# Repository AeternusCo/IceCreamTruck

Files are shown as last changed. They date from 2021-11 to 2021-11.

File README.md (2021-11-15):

# Ice Cream Truck

A drop-in replacement PCB for Minivan cases with choc v1 switches.

**N.B.** At the date of publication, some keys don't exist so they'll either need to use smaller key sizes or 3d printed keys.

PCB has been tested, but order at your own risk.

## Features

- STM32F072 (or F042) MCU
- Drop-in compatibility with existing minivan cases
- Choc v1 switch footprints

## Firmware

ICT runs QMK. Firmware has not been merged into upstream, but should be available in the AeternusCo fork [here](https://github.com/AeternusCo/qmk_firmware).

## Ordering

Generate gerbers, upload to fab house of your choice, pay.

## Images

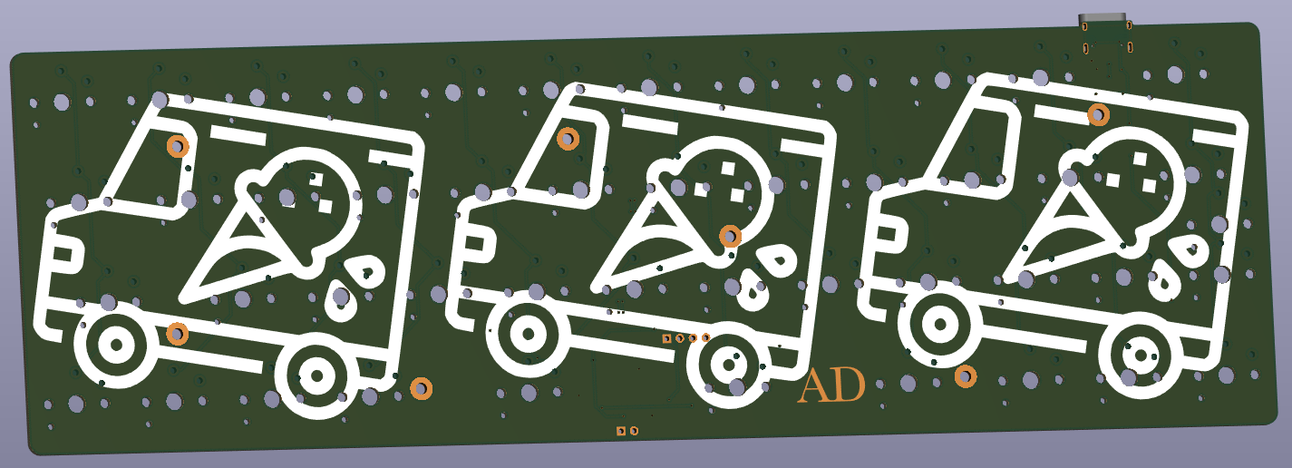
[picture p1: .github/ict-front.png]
PCB Front


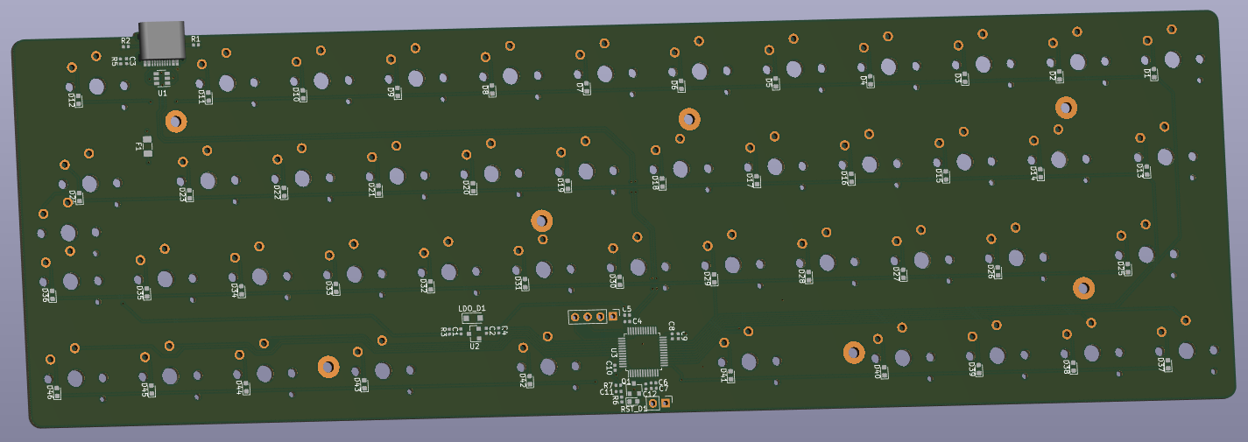
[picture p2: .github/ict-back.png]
PCB Back


## License

All files are licensed under CERN-OHL-P v2.

See [LICENSE](/LICENSE) file for more details.

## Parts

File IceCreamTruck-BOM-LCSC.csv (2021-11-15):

Id | Comment | Designator | Footprint | Quantity | LCSC Part Number
5 | 1N4148W | D38,D39,D37,D45,D46,D44,D16,D15,D13,D14,D8,D6,D7,D3,D4,D5,D2,D17,D18,D19,D20,D25,D26,D27,D28,D29,D30,D31,D32,RST_D1,D10,D12,D11,D9,D1,D22,D21,D23,D24,D33,D34,D35,D36,D40,D41,D43,D42 | 0603 | 47 | C109002
8 | STM32F072CBTx | U3 | LQFP-48_7.0x7.0x0.5P | 1 | C88447
9 | SRV05-4 | U1 | SOT-23-6 | 1 | C85364
10 | MCP1700T-3302E_SOT23 | U2 | SOT-23-3 | 1 | C39051
11 | 10u | C7,C11 | 0402 | 2 | C15525
12 | 1u | C1,C2,C6 | 0402 | 3 | C52923
13 | 4.7n | C3 | 0402 | 1 | C1538
14 | 100nF | C8,C4,C9,C12 | 0402 | 4 | C1525
15 | 4.7u | C5,C10 | 0402 | 2 | C23733
16 | 5k1 | R2,R1 | 0402 | 2 | C25905
17 | DTC123JKAT146 | Q1 | SOT-23-3 | 1 | C111724
22 | 100k | R3,R4 | 0402 | 2 | C25741
23 | 330k | R6 | 0402 | 1 | C25779
24 | 1M | R5,R7 | 0402 | 2 | C26083

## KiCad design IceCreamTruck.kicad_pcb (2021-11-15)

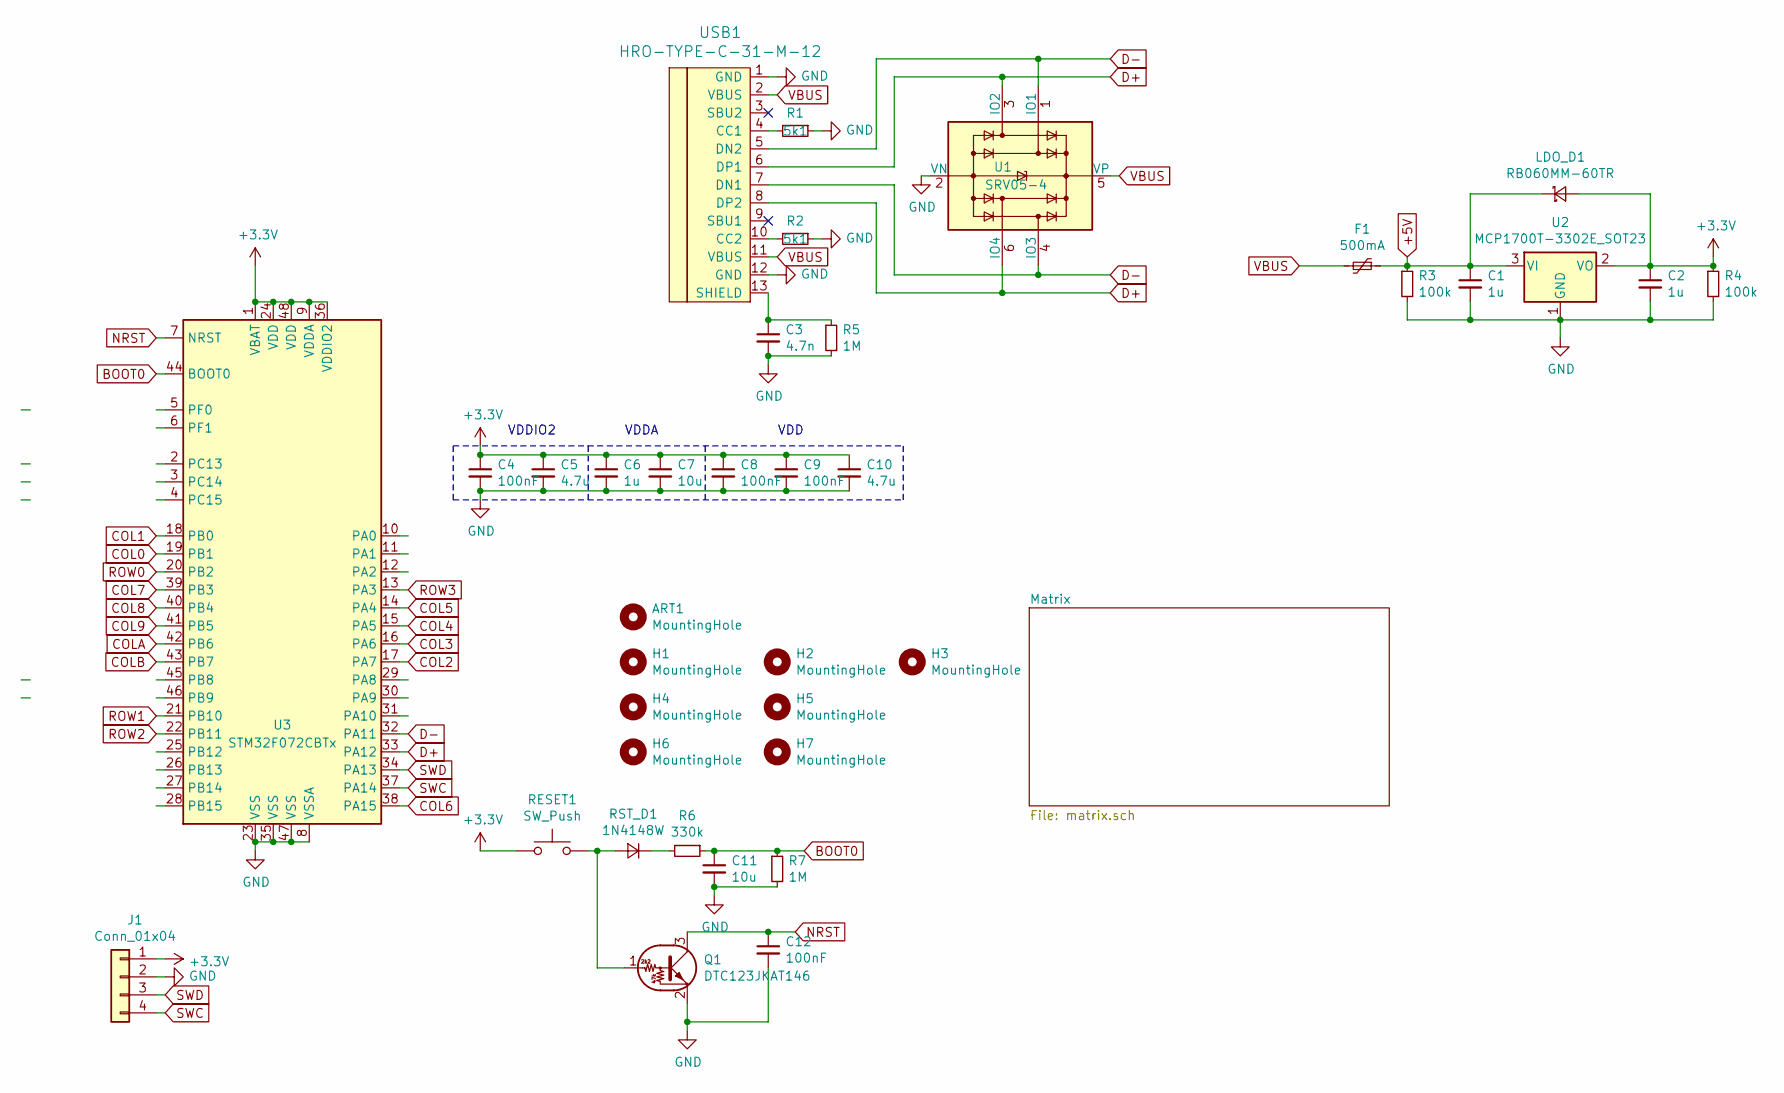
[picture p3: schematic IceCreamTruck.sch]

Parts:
ART1: MountingHole; AeternusDecorumLogo18x18
C1, C2, C6: 1u; C_0402_1005Metric
C3: 4.7n; C_0402_1005Metric
C4, C8, C9, C12: 100nF; C_0402_1005Metric
C5, C10: 4.7u; C_0402_1005Metric
C7, C11: 10u; C_0402_1005Metric
F1: 500mA; Fuse_1206_3216Metric
H1, H2, H3, H4, H5, H6, H7: MountingHole; MountingHole_2.2mm_M2_Pad
J1: Conn_01x04; PinHeader_1x04_P2.54mm_Vertical
LDO_D1: RB060MM-60TR; D_SOD-123F
Q1: DTC123JKAT146; SOT-23
R1, R2: 5k1; R_0402_1005Metric
R3, R4: 100k; R_0402_1005Metric
R5, R7: 1M; R_0402_1005Metric
R6: 330k; R_0402_1005Metric
RESET1: SW_Push; PinHeader_1x02_P2.54mm_Vertical
RST_D1: 1N4148W; D_0603_1608Metric
U1: SRV05-4; SOT-23-6
U2: MCP1700T-3302E_SOT23; SOT-23
U3: STM32F072CBTx; LQFP-48_7x7mm_P0.5mm
USB1: HRO-TYPE-C-31-M-12

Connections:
+3V3: C2.1, C4.1, C5.1, C6.1, C7.1, C8.1, C9.1, C10.1, J1.1, LDO_D1.2 (A), R4.1, RESET1.1, U2.2 (VO), U3.1 (VBAT), U3.9 (VDDA), U3.24 (VDD), U3.36 (VDDIO2), U3.48 (VDD)
+5V: C1.1, F1.1, LDO_D1.1 (K), R3.1, U2.3 (VI)
BOOT0: C11.1, R6.1, R7.1, U3.44 (BOOT0)
COL0: U3.19 (PB1); also elsewhere on the board
COL1: U3.18 (PB0); also elsewhere on the board
COL2: U3.17 (PA7); also elsewhere on the board
COL3: U3.16 (PA6); also elsewhere on the board
COL4: U3.15 (PA5); also elsewhere on the board
COL5: U3.14 (PA4); also elsewhere on the board
COL6: U3.38 (PA15); also elsewhere on the board
COL7: U3.39 (PB3); also elsewhere on the board
COL8: U3.40 (PB4); also elsewhere on the board
COL9: U3.41 (PB5); also elsewhere on the board
COLA: U3.42 (PB6); also elsewhere on the board
COLB: U3.43 (PB7); also elsewhere on the board
D+: U1.3 (IO2), U1.6 (IO4), U3.33 (PA12), USB1.6 (DP1), USB1.8 (DP2)
D-: U1.1 (IO1), U1.4 (IO3), U3.32 (PA11), USB1.5 (DN2), USB1.7 (DN1)
GND: C1.2, C2.2, C3.2, C4.2, C5.2, C6.2, C7.2, C8.2, C9.2, C10.2, C11.2, C12.2, J1.2, Q1.2 (E), R1.1, R2.1, R3.2, R4.2, R5.2, R7.2, U1.2 (VN), U2.1 (GND), U3.8 (VSSA), U3.23 (VSS), U3.35 (VSS), U3.47 (VSS), USB1.1 (GND), USB1.12 (GND)
NRST: C12.1, Q1.3 (C), U3.7 (NRST)
unnamed: C3.1, R5.1, USB1.13 (SHIELD)
unnamed: Q1.1 (B), RESET1.2, RST_D1.2 (A)
unnamed: R1.2, USB1.4 (CC1)
unnamed: R2.2, USB1.10 (CC2)
unnamed: R6.2, RST_D1.1 (K)
ROW0: U3.20 (PB2); also elsewhere on the board
ROW1: U3.21 (PB10); also elsewhere on the board
ROW2: U3.22 (PB11); also elsewhere on the board
ROW3: U3.13 (PA3); also elsewhere on the board
SWC: J1.4, U3.37 (PA14)
SWD: J1.3, U3.34 (PA13)
VBUS: F1.2, U1.5 (VP), USB1.2 (VBUS), USB1.11 (VBUS)

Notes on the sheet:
VDDIO2
VDDA
VDD

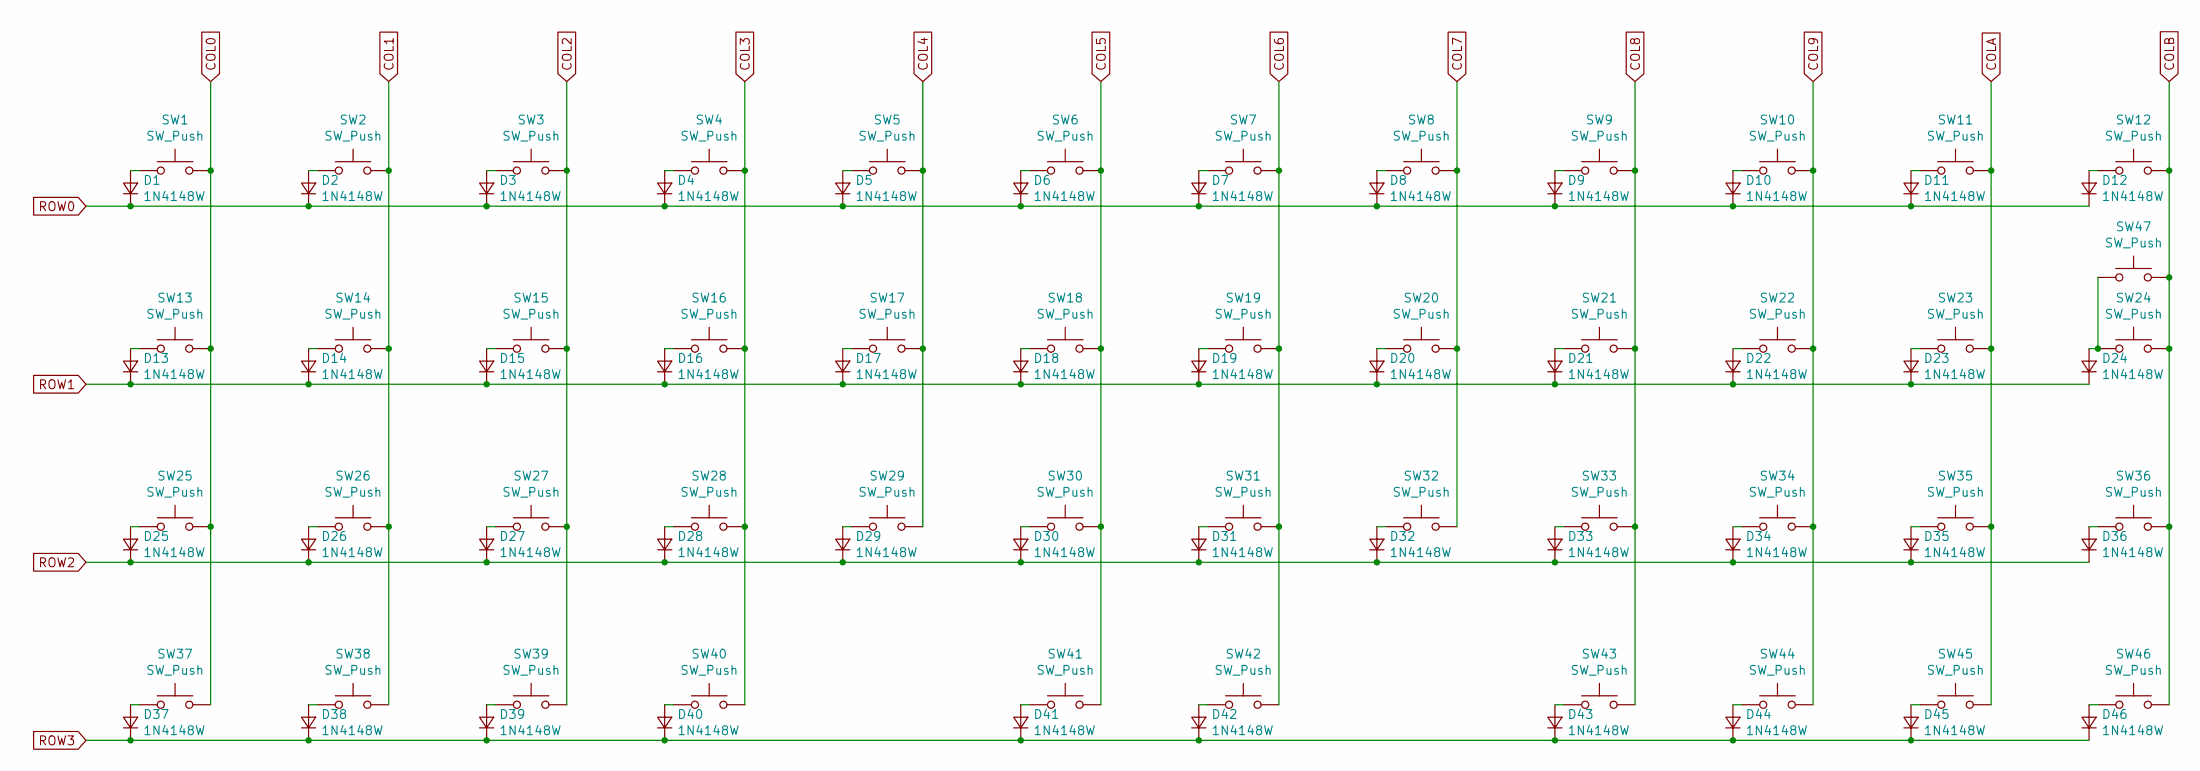
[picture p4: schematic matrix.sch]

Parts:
D1, D2, D3, D4, D5, D6, D7, D8, D9, D10, D11, D12, D13, D14, D15, D16, D17, D18, D19, D20, D21, D22, D23, D24, D25, D26, D27, D28, D29, D30, D31, D32, D33, D34, D35, D36, D37, D38, D39, D40, D41, D42, D43, D44, D45, D46: 1N4148W; D_0603_1608Metric
SW1, SW2, SW3, SW4, SW5, SW6, SW7, SW8, SW9, SW10, SW11, SW14, SW15, SW16, SW17, SW18, SW19, SW20, SW21, SW22, SW23, SW26, SW27, SW28, SW29, SW30, SW31, SW32, SW33, SW34, SW35, SW36, SW37, SW38, SW39, SW40, SW41, SW42, SW44, SW45, SW46, SW47: SW_Push; KailhChoc-1U
SW12, SW25: SW_Push; KailhChoc-1.75U
SW13: SW_Push; KailhChoc-1.25U
SW24, SW43: SW_Push; KailhChoc-1.5U

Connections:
COL0: SW1.2, SW13.2, SW25.2, SW37.2; also elsewhere on the board
COL1: SW2.2, SW14.2, SW26.2, SW38.2; also elsewhere on the board
COL2: SW3.2, SW15.2, SW27.2, SW39.2; also elsewhere on the board
COL3: SW4.2, SW16.2, SW28.2, SW40.2; also elsewhere on the board
COL4: SW5.2, SW17.2, SW29.2; also elsewhere on the board
COL5: SW6.2, SW18.2, SW30.2, SW41.2; also elsewhere on the board
COL6: SW7.2, SW19.2, SW31.2, SW42.2; also elsewhere on the board
COL7: SW8.2, SW20.2, SW32.2; also elsewhere on the board
COL8: SW9.2, SW21.2, SW33.2, SW43.2; also elsewhere on the board
COL9: SW10.2, SW22.2, SW34.2, SW44.2; also elsewhere on the board
COLA: SW11.2, SW23.2, SW35.2, SW45.2; also elsewhere on the board
COLB: SW12.2, SW24.2, SW36.2, SW46.2, SW47.2; also elsewhere on the board
unnamed: D1.2 (A), SW1.1
unnamed: D2.2 (A), SW2.1
unnamed: D3.2 (A), SW3.1
unnamed: D4.2 (A), SW4.1
unnamed: D5.2 (A), SW5.1
unnamed: D6.2 (A), SW6.1
unnamed: D7.2 (A), SW7.1
unnamed: D8.2 (A), SW8.1
unnamed: D9.2 (A), SW9.1
unnamed: D10.2 (A), SW10.1
unnamed: D11.2 (A), SW11.1
unnamed: D12.2 (A), SW12.1
unnamed: D13.2 (A), SW13.1
unnamed: D14.2 (A), SW14.1
unnamed: D15.2 (A), SW15.1
unnamed: D16.2 (A), SW16.1
unnamed: D17.2 (A), SW17.1
unnamed: D18.2 (A), SW18.1
unnamed: D19.2 (A), SW19.1
unnamed: D20.2 (A), SW20.1
unnamed: D21.2 (A), SW21.1
unnamed: D22.2 (A), SW22.1
unnamed: D23.2 (A), SW23.1
unnamed: D24.2 (A), SW24.1, SW47.1
unnamed: D25.2 (A), SW25.1
unnamed: D26.2 (A), SW26.1
unnamed: D27.2 (A), SW27.1
unnamed: D28.2 (A), SW28.1
unnamed: D29.2 (A), SW29.1
unnamed: D30.2 (A), SW30.1
unnamed: D31.2 (A), SW31.1
unnamed: D32.2 (A), SW32.1
unnamed: D33.2 (A), SW33.1
unnamed: D34.2 (A), SW34.1
unnamed: D35.2 (A), SW35.1
unnamed: D36.2 (A), SW36.1
unnamed: D37.2 (A), SW37.1
unnamed: D38.2 (A), SW38.1
unnamed: D39.2 (A), SW39.1
unnamed: D40.2 (A), SW40.1
unnamed: D41.2 (A), SW41.1
unnamed: D42.2 (A), SW42.1
unnamed: D43.2 (A), SW43.1
unnamed: D44.2 (A), SW44.1
unnamed: D45.2 (A), SW45.1
unnamed: D46.2 (A), SW46.1
ROW0: D1.1 (K), D2.1 (K), D3.1 (K), D4.1 (K), D5.1 (K), D6.1 (K), D7.1 (K), D8.1 (K), D9.1 (K), D10.1 (K), D11.1 (K), D12.1 (K); also elsewhere on the board
ROW1: D13.1 (K), D14.1 (K), D15.1 (K), D16.1 (K), D17.1 (K), D18.1 (K), D19.1 (K), D20.1 (K), D21.1 (K), D22.1 (K), D23.1 (K), D24.1 (K); also elsewhere on the board
ROW2: D25.1 (K), D26.1 (K), D27.1 (K), D28.1 (K), D29.1 (K), D30.1 (K), D31.1 (K), D32.1 (K), D33.1 (K), D34.1 (K), D35.1 (K), D36.1 (K); also elsewhere on the board
ROW3: D37.1 (K), D38.1 (K), D39.1 (K), D40.1 (K), D41.1 (K), D42.1 (K), D43.1 (K), D44.1 (K), D45.1 (K), D46.1 (K); also elsewhere on the board

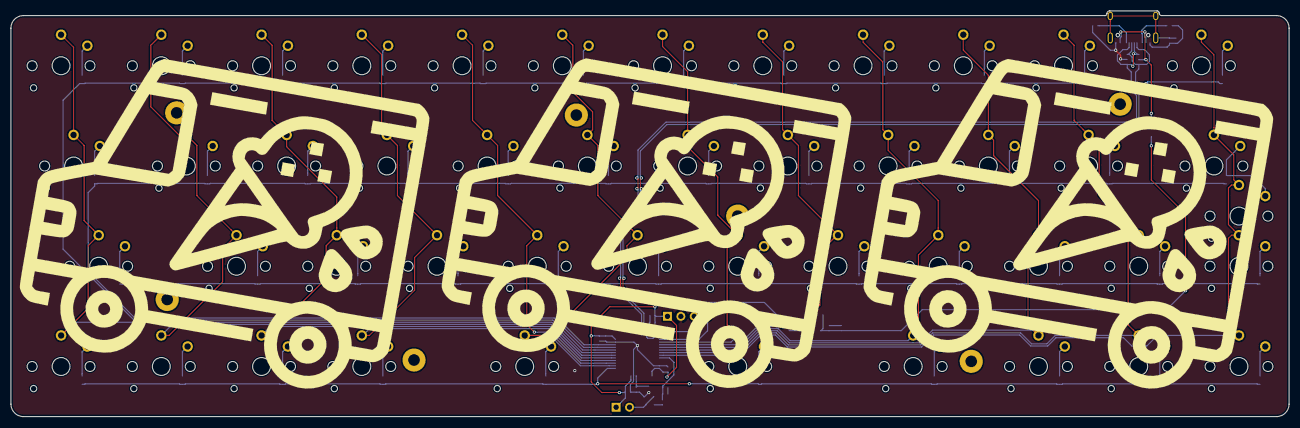
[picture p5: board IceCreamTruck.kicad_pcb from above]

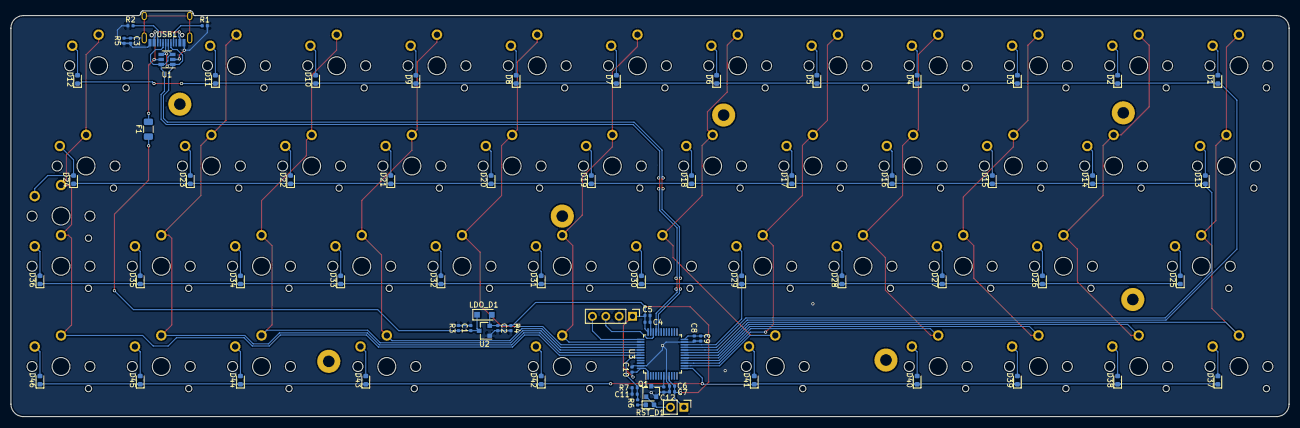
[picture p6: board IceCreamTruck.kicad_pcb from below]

Board: 2 copper layers, 242.9 x 77.1 mm, 130 parts (75 on the bottom side), 77 nets.
